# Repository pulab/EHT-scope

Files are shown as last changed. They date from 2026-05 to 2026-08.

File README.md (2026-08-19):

# EHT-scope
**Engineered heart tissue imaging platform with acquisition and analysis software**

The platform is designed to image engineered heart tissues suspended on flexible posts in a 24 well dish.

## Components

* **EHT-scope Hardware Build**: Instructions and schematics to build the imaging platform
* **Code**: Software for acquisition, tracking, and analysis
  * **EHT-acquire**: Code for data acquisition using EHT-scope hardware
  * **EHT-analyze**: MATLAB scripts to analyze post positions and calculate physiological parameters

## Workflow (MATLAB-Based)

1.  **Acquisition**: (`EHT-acquire_v2.bsh`): Automated 24-well plate imaging with pacing protocols using EHT-scope hardware
2.  **Motion Tracking** (`EHT_motion_tracker.m`): Template-based post position tracking
3.  **Force Analysis** (`multi_pacing_analysis.m`): Calculate force, contraction/relaxation kinetics, and beat metrics

## Key Features
- **No ImageJ dependency** - all tracking and analysis handled entirely in MATLAB
- **Automated batch processing** of multiple wells and pacing frequencies
- **Dynamic self-calibrating diastolic baseline** computation to auto-correct for tracking offsets
- **Physiological parameter extraction** (force, beat rate, kinetics, T50, C50, R50)
- **Customizable** for different tissue geometries and spacing (configured in `EHT_config.m`)

## Getting Started

See `Code/EHT-analyze/README.md` for detailed usage instructions and **critical template-drawing guidelines.**

## Example Data and Results

Example image sequences and representative results are available in the latest GitHub release:

https://github.com/pulab/EHT-scope/releases/latest

Download `Supplementary Data 4.zip` from the release assets. The archive contains:

- `Analysis_Code`: analysis code included with the supplementary package
- `Representative_Image_Sequences`: example raw image sequences
- `Results`: representative tracking and force-analysis output files

To run the example data, extract the zip file, add `Code/EHT-analyze` to the MATLAB path, and use the extracted `Representative_Image_Sequences` folder as the input data folder.

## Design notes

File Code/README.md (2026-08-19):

# EHT-scope Code - MATLAB Workflow
Authors: William Pu (EHT-acquire) and Kushaan Sharma (EHT-scope).

This folder contains all the code for the EHT-scope platform using a unified MATLAB workflow.

## Overview

The workflow consists of three main stages:
1. **Image Acquisition** - EHT-acquire: Automated imaging via MicroManager (BeanShell)
2. **Motion Tracking** - EHT-scope: Post position tracking using MATLAB Image Processing Toolbox
3. **Motion Analysis** - EHT-scope: Physiological parameter calculation in MATLAB

## Files

### EHT-acquire
#### Arduino Controller
- **EHT_controller.ino**: Arduino sketch for controlling optical pacer, focus motor, and illumination
#### Acquisition
- **EHT_acqure_v2.bsh**: BeanShell script for automated acquisition via MicroManager
- **BaslerCameraInitialize.bsh**: BeanShell script to initialize the Basler Camera

### Motion Tracking (MATLAB)
- **EHT-analyze/EHT_motion_tracker.m**: Main motion tracking function

### Force Analysis (MATLAB)
- **EHT-analyze/multi_pacing_analysis.m**: Main analysis script
- **EHT-analyze/analyze_EHT_with_figure.m**: Detailed analysis and plotting
- **EHT-analyze/post_force2.m**: Force calculation from post deflection
- **EHT-analyze/find_pv7.m**: Peak and valley detection
- **EHT-analyze/peakdet2.m**: Peak detection algorithm
- **EHT-analyze/sgolayfilt.m**: Savitzky-Golay filter
- **EHT-analyze/analyze_slopes.m**: Contraction/relaxation slope analysis
- **EHT-analyze/detect_maxmin.m**: Helper wrapper function
- **EHT-analyze/calculate_slopes.m**: Helper wrapper function

## Requirements

### MATLAB
- MATLAB R2016b or later
- Image Processing Toolbox

### MicroManager (for acquisition only)
- MicroManager 1.4
- Compatible camera and motorized stage

## Quick Start

### 1. Acquisition
Run `EHT_acqure_v2.bsh` in MicroManager to capture images.

### 2. Motion Tracking
```matlab
% In MATLAB, navigate to Code/EHT-analyze/
EHT_motion_tracker()
```

### 3. Force Analysis
```matlab
% In MATLAB
multi_pacing_analysis()
```

## Data Flow

```
Raw Images (TIF) 
    ↓ (MicroManager)
Image Folders + Metadata
    ↓ (EHT_motion_tracker.m)
Post Positions (TXT)
    ↓ (multi_pacing_analysis.m)
Force Metrics (TXT) + Plots (FIG)
```

## Documentation

See **EHT-analyze/README.md** for comprehensive documentation including:
- Detailed usage instructions
- Parameter descriptions
- Calibration procedures
- Troubleshooting guide
- Example workflows

## Advantages of MATLAB Workflow

✓ **No ImageJ dependency**: All processing in MATLAB  
✓ **Unified environment**: One platform for all analysis  
✓ **Powerful visualization**: MATLAB plotting and export  
✓ **Academic standard**: Widely used in research  
✓ **Reproducible**: Version-controlled analysis scripts  

## Support

For detailed help, see `EHT-analyze/README.md` in this directory.

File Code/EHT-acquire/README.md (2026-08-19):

# EHT-acquire
- code needed to run the EHT-scope hardware and automate acquisition from a 24-well plate
- requires Micromanager 1.4

## EHT_controller.ino
- arduino sketch to run the arduino user interface of EHT-scope

## EHT_acquire_v2.bsh
- Micromanager 1.4 beanshell script for automated acquisition

## BaslerCameraInitialize.bsh
- Micromanager 1.4 beanshell script to configure the Basler Camera

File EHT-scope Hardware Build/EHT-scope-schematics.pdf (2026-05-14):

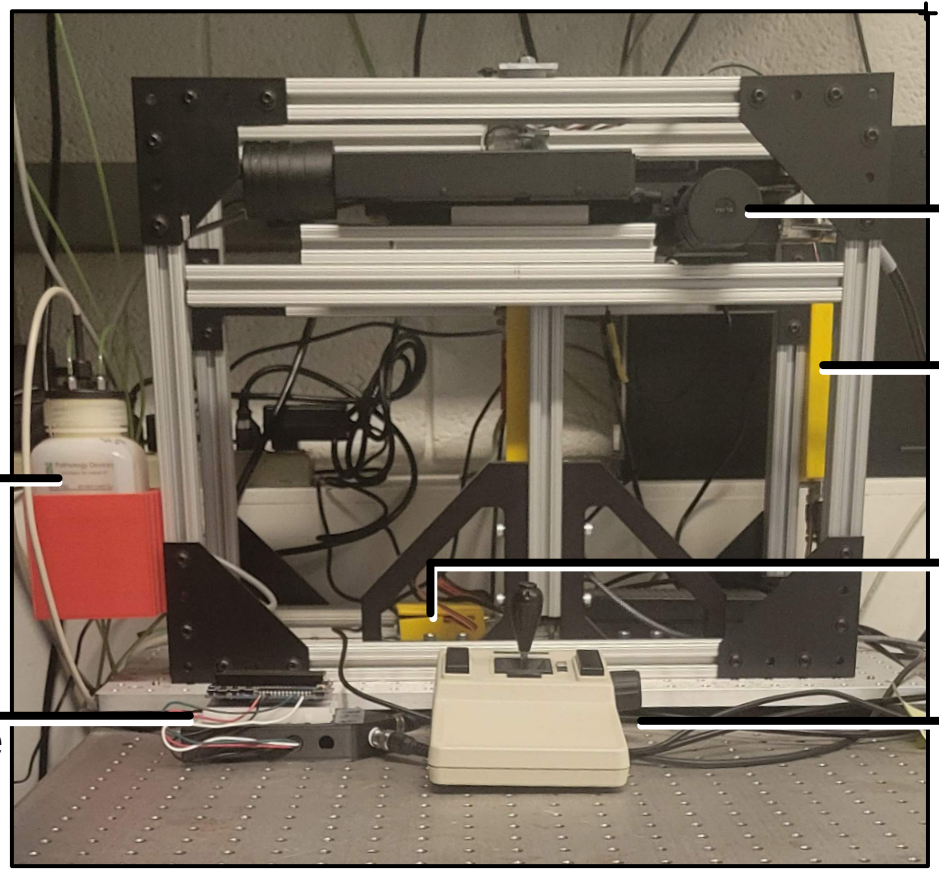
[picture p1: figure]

Mechanical
Stage (Prior)

LED power

Prior XY
stage

Actuator
Controller

Stage
Controller

Lens

Ring light (white light)
and lens mount

Blue light filter

Blue LEDs on
aluminum heatsink/
support

Camera

Camera Mount

Actuator Mount

Linear Actuator

a

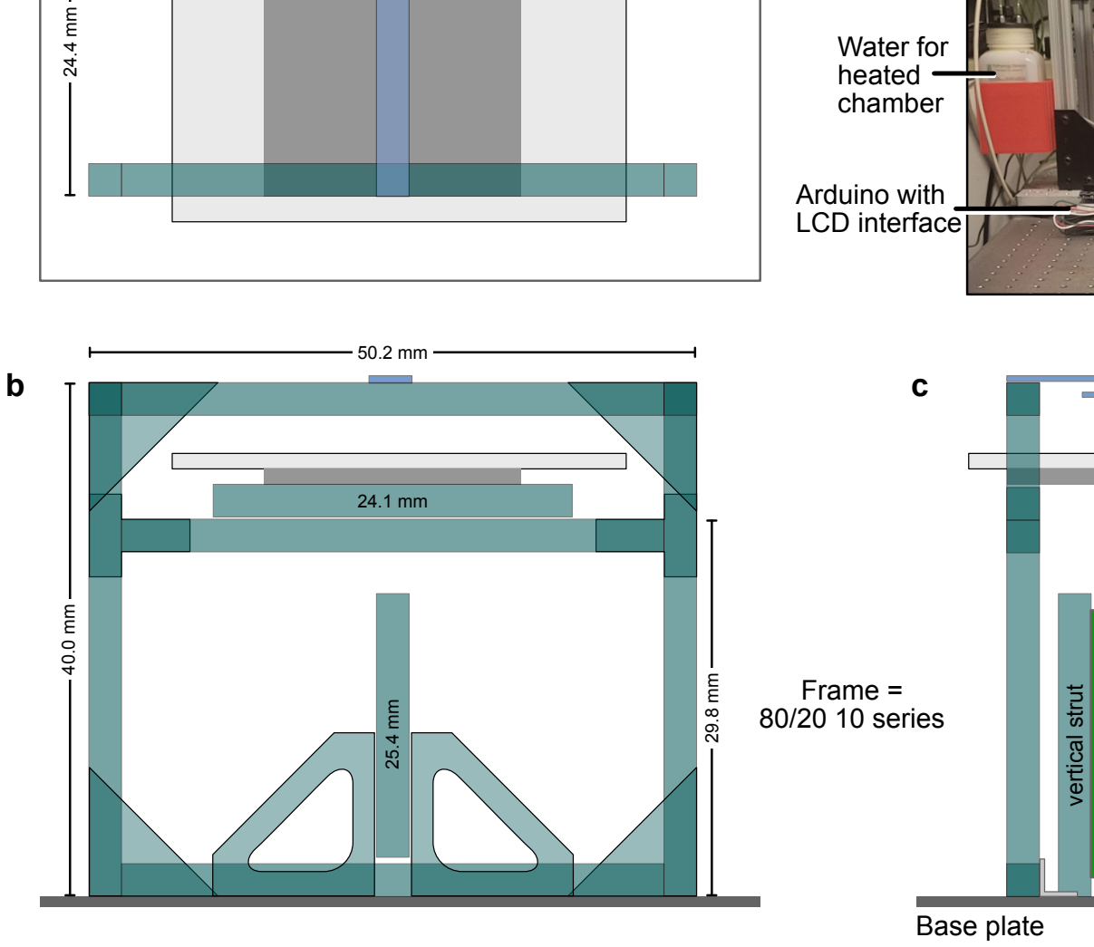
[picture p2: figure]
Base plate; Frame = 80/20 10 series; Water for heated chamber; vertical strut; Arduino with LCD interface

Figure 1. EHT assay device design. a-c. Schematic top (a), front (b), and side (c) views showing the 80/20 extruded aluminum frame supporting the mechanical stage. The side view details the camera attachment to a linear actuator through 3D printed mounts. A 3D printed attachment to the top of the lens holds a white LED ring light and a blue long-pass filter. The blue pacing LEDs are mounted above the stage under an aluminum heatsink/support. d. EHT assay device photo taken from the front.

d

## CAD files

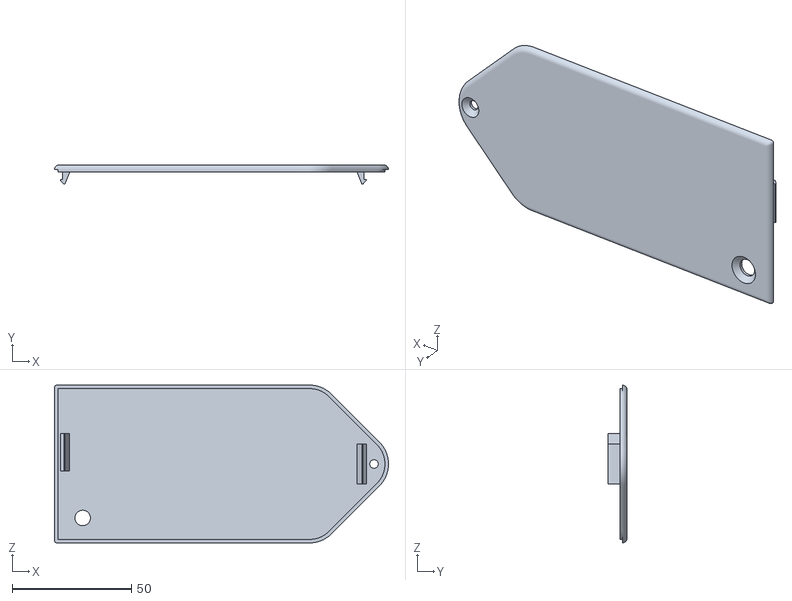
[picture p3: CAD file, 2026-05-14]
EHT-scope Hardware Build/Arduino simple 4 channel ttl top.stl
140.2 x 8.00 x 66.3

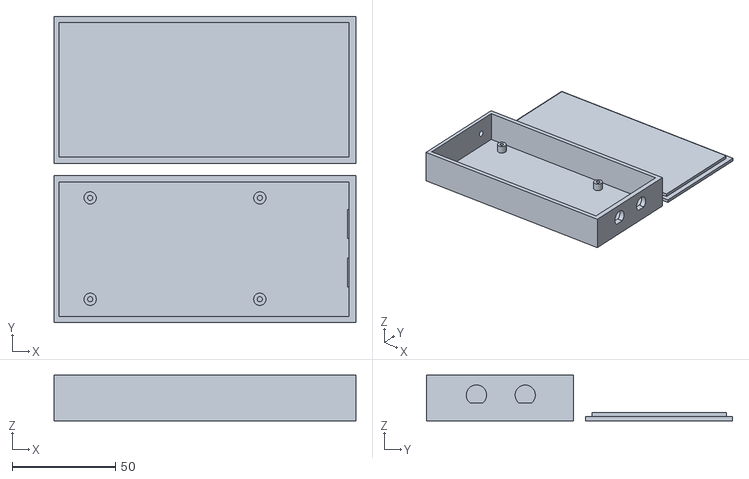
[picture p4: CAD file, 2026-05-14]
EHT-scope Hardware Build/LED_Power_holder.stl
146.0 x 148.0 x 22.0

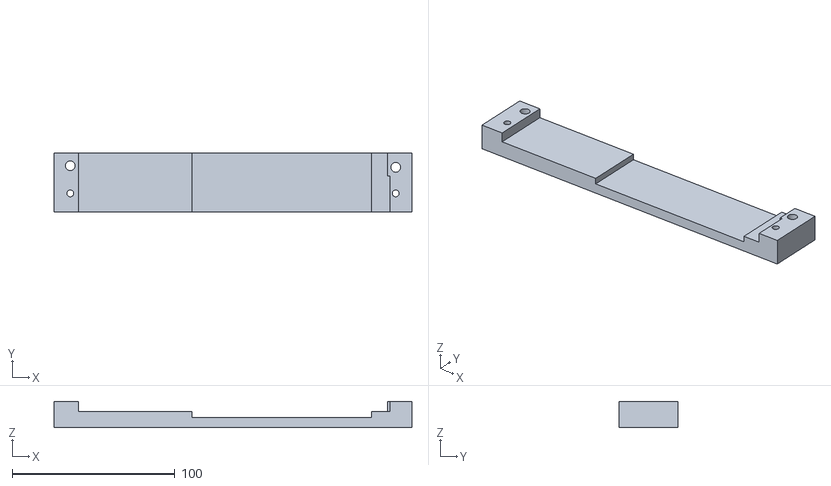
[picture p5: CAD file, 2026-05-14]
EHT-scope Hardware Build/ActuatorHolderV2.stl
220.0 x 36.0 x 16.0

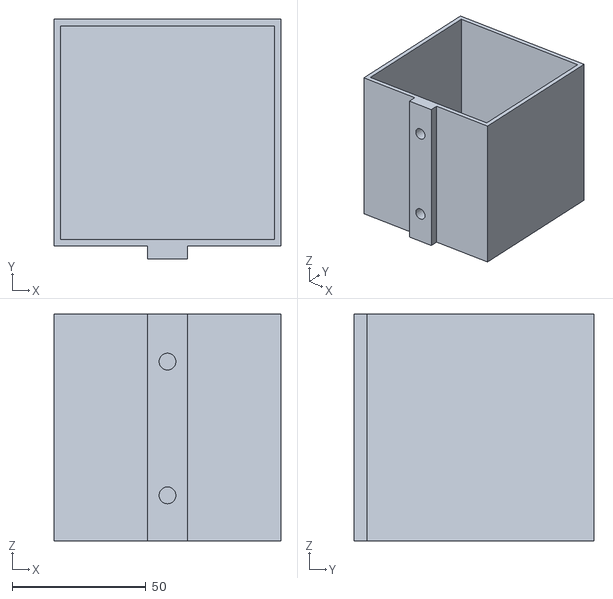
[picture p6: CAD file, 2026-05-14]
EHT-scope Hardware Build/stagetop bottle holder.stl
85.0 x 89.7 x 85.0

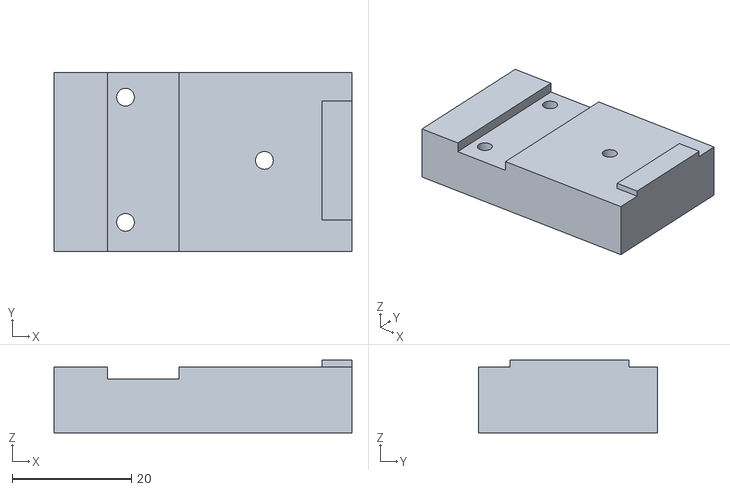
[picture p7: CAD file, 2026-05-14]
EHT-scope Hardware Build/CameraMountv2.stl
50.0 x 30.0 x 12.2

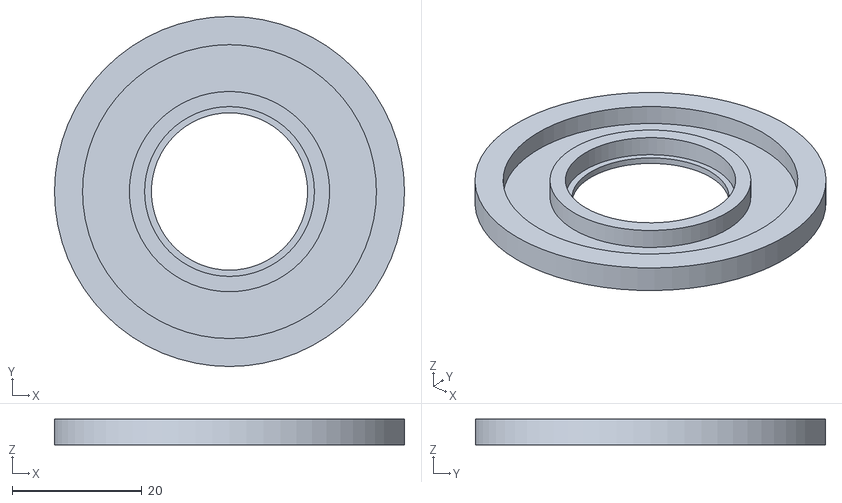
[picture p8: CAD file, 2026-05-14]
EHT-scope Hardware Build/LED_LPFilter_holder -- 54 mm -- slip.stl
53.9 x 53.9 x 4.00

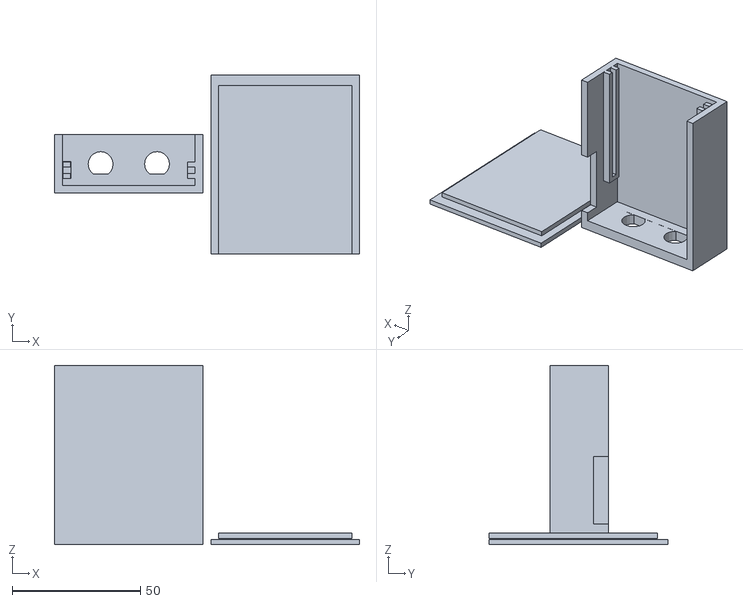
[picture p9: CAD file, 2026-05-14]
EHT-scope Hardware Build/LinearActuatorController_Holder.stl
119.0 x 70.0 x 70.0

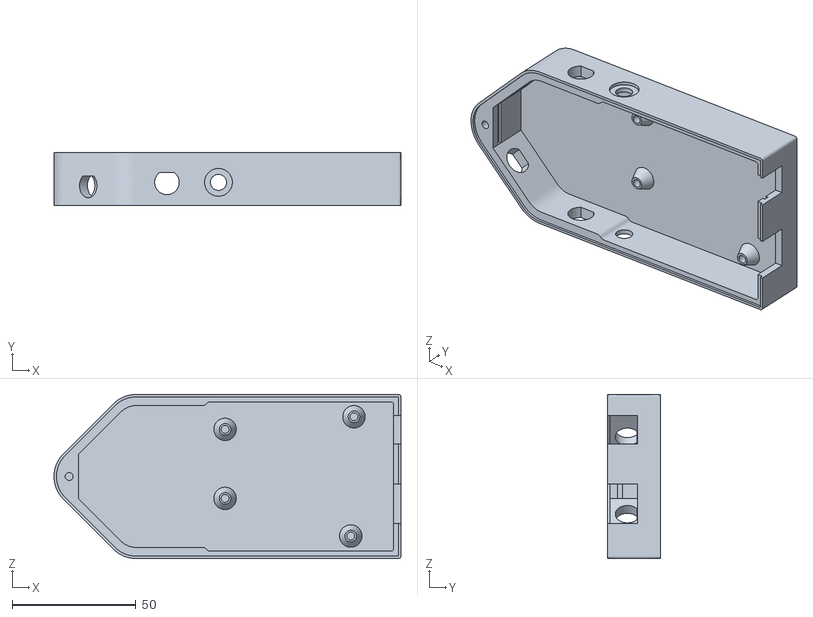
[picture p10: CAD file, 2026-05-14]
EHT-scope Hardware Build/Arduino simple 4 channel ttl bottom.stl
140.2 x 21.3 x 66.3

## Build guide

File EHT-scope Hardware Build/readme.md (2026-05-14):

**Introduction**

The EHT assay device consists of several components:

- A frame that supports a mechanical stage above a video camera. There is white light illumination for the video camera and a high intensity blue LED for optical pacing.
- An Arduino running software (EHT-controller) that controls the camera, optical pacer, and white light illumination.
- A PC connected to the mechanical stage and the Arduino. Using MicroManager as the hardware controller and the BeanShell script EHT-acquire, the PC automates multiwell acquisition.
- Post-acquisition video analysis using MATLAB (EHT_motion_tracker) to yield EHT post positions over time.
- Force analysis in MATLAB (analyze_EHT), which analyzes post position vs time to calculate contraction and relaxation kinetics and force.

**Software Workflow:**
1. Image acquisition: MicroManager with BeanShell script (`EHT_acqure_v2.bsh`)
2. Motion tracking: MATLAB (`EHT_motion_tracker.m`)
3. Force analysis: MATLAB (`analyze_EHT.m`)

All analysis is now performed in MATLAB for a unified workflow. See `Code/README_MATLAB.md` for detailed software documentation.

**Assembly of the EHT assay device.**

Refer to ItemList.xlsx and EHT-scope-schematics.pdf

1. **Assemble the EHT assay device frame (See Fig. 1)**

Assemble the frame for the device using 80/20 10 series profiles, following the schematics in Fig. 1. Cut the profiles to length using a miter saw with a blade for cutting aluminum. This frame holds the mechanical stage above the camera and lens and below the pacing LEDs. The frame dimensions should be adjusted to fit the select XY stage.

2. **Attach the frame to the aluminum base plate (See Fig. 1)**

Attach the rubber damping feet to the aluminum base plate.

Use the right angle brackets to attach the 80/20 frame to the base plate.

Use two 6” vertical brackets to attach the vertical strut to the base plate.

3. **Attach the mechanical stage to the frame (See Fig. 1)**

We used a spare Prior H101A stage. This stage was designed for an upright microscope and needed modifications to work in this inverted application. It would be better to use a stage designed for an inverted microscope.

4. **Assemble the camera and lens (See Fig. 2)**

3D print the mount that holds the ring light and long pass filter on the lens. Use a glue gun to attach the ring light and long pass filter to the mount. Solder long wires to the ring light. The mount fits into the threads on the end of the lens. Attach the lens to the camera. Mount the camera on the linear actuator using the 3D printed camera mount. Mount the linear actuator to the vertical strut using the 3D printed actuator holder. Wire the linear actuator to its controller and its AC/DC transformer, following the instructions on the Actuonix website. Solder the ground and signal wires to a BNC cabinet connector.

5. **Assemble the pacing LEDs (see Fig. 3 and 4)**

Place the Teflon sliders in the T-tracks on the top rails of the frame. Also put the stopper bolts into these T-tracks. Cut one aluminum bar so it spans the frame and a shorter aluminum bar about ½ the length of the first. Drill holes in the longer aluminum bar, one pair for the bolts on the Teflon sliders, and one pair to mount the shorter bar. Cut slots into the shorter bar so that its position can be adjusted with respect to the upper bar. Attach the 2 blue pacing LEDs using thermal epoxy. Solder long wires to the blue pacing LEDs. Snap the lens covers on the pacing LEDs. Mount the shorter bar under the longer using screws, springs, and wing nut. This will allow you to be able to adjust the height and location of the pacing lights so that it is centered above the camera and just above the top of the stage top incubator. Use the long wires to connect the pacing lights to the high-power LED drivers, mounted in the 3D printed LED driver case. Solder the LED driver inputs to BNC cabinet connectors. Pass the long wires from the ring light into the LED driver case and solder them to BNC cabinet connectors. Inside the LED driver case, connect the 12V AC/DC transformer to the LED drivers and connect the ring light AD/DC transformer to the long wires from the ring light.

6. **Assemble the Arduino (See Fig. 4)**

3D print the Arduino case. Build the RGB LCD shield, which is the user interface for the Arduino. Instructions on Adafruit website. Wire the Arduino as follows: Pin 5 for white LED ring light. Pin 6, Blue pacing LEDs. Pin 10, linear actuator. Each of these wires is soldered to the central terminal on a cabinet BNC connector, attached to the Arduino case. Solder a wire to each of the 3 outer BNC terminals. Solder the other end to a wire from the GND. Wire the RGB LCD shield. On the RGB shield board, we refer to the bottom row of 12 holes counting left to right, with the hole nearest the reset button being 12. Red from hole 3 to Arduino 5V. Black from hole 5 to Arduino GND (next to the 5V pin). Green from hole 11 to Arduino A4. White from hole 12 to Arduino A5. Use BNC connectors to connect the Arduino to the pacing LED driver, white LED ring light, and linear actuator.

Plug the Arduino into the computer using a USB cable. Upload EHT-controller.ino to the Arduino.

7. **Configure EHT-assay-device.**

Unplug and plug in the USB connector to the Arduino. The code should run. Use keys next to the LCD to select focus. Adjust the position of the camera using the up and down arrows on the Arduino so that the camera is focused on the EHT posts when they are placed within 24w dish inside the stage incubator. Adjust the height of the pacing assembly and center the pacing LEDs over the center of the lens. Make sure that the mechanical stage can move all of the well positions over the lens center.

8. **Install and configure micromanager.**

Install Basler camera pylon 6 SDK. Install micromanager 1.4. Configure it to use the Prior stage, the Basler camera, and the Arduino-Hub. Load and run the BeanShell code for EHT-acquire, which controls automated image acquisition. On the Arduino, select the “Run” option so that the computer can control the acquisition.

9. **Configure MATLAB for post motion analysis**

Install MATLAB (R2016b or later) with the following toolboxes:
- Image Processing Toolbox
- Curve Fitting Toolbox

The MATLAB code for motion tracking and force analysis is located in the `Code/EHT-analyze/` folder:
- **EHT_motion_tracker.m** - Analyzes EHT video images and yields a table of position vs time
- **EHT_motion_tracker_gui.m** - GUI interface for motion tracking
- **analyze_EHT.m** - Analyzes post position vs time to calculate contraction/relaxation kinetics and force

**Quick Start:**
```matlab
% In MATLAB, navigate to Code/EHT-analyze/
EHT_motion_tracker_gui()  % Run motion tracking with GUI
```

See `Code/README_MATLAB.md` for detailed installation and usage instructions.

**Note:** The previous ImageJ/Fiji-based workflow has been replaced with a unified MATLAB workflow for easier use and better integration.

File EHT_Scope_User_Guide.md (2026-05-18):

# EHT-Scope User Guide (Quick Start)
**Standardized Analysis Workflow for EHT Videos**

---

## 1. Before You Start
Make sure your data is organized correctly on your computer:
*   **Raw Videos**: Place your video folders inside the `TestingData` folder.
*   **Folder Names**: Ensure folders are named like this: `Acquire-EHT_WellName_PacingRate` (Example: `Acquire-EHT_A1_60`).

For the manuscript example data and results, download `Supplementary Data 4.zip` from the latest GitHub release:

https://github.com/pulab/EHT-scope/releases/latest

After extracting the zip file, use `Representative_Image_Sequences` as the input data folder. The `Results` folder contains representative tracking and force-analysis outputs.

---

## 2. Step 1: Tracking the Tissue (Motion Tracking)
To identify the posts in your video, run the following command in the MATLAB Command Window. 

**Note**: You must be in the main project folder.

```matlab
% 1. Add the code folder to your MATLAB path
addpath('Code/EHT-analyze');

% 2. Run the tracking command (This example tracks ALL folders in TestingData)
EHT_motion_tracker('Templates', 'TestingData', 'Results', true, 'Code/EHT-analyze/EHT_config.m', true, {});
```
*   **Post Selection**: A window will open for each new well. Click and drag boxes around the **left post** and **right post**.
*   **Automatic Matching**: The software will automatically apply your boxes to all pacing rates (0, 60, 120) for that well.

---

## 3. Step 2: Getting the Results (Force Analysis)
Once tracking is finished, run the analysis command:

```matlab
multi_pacing_analysis
```
When prompted, enter the full path to the `Results` folder created by the motion-tracking step.
*   **Individual Results**: Saved in the `Results` folder as `.txt` files for each tissue and pacing rate.
*   **Figures**: Saved in the `Results` folder as MATLAB `.fig` files.

---

## 4. Standard Settings
To change baseline settings, edit the file `Code/EHT-analyze/EHT_config.m`:
*   **Pixel Size**: Should be **67** (Pixels per mm).
*   **Diastolic Distance**: Should be **8.0** mm.

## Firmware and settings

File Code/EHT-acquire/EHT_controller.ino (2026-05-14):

#include <Adafruit_MCP4725.h>

#include <Adafruit_RGBLCDShield.h>
#include <Servo.h>
#include <Adafruit_NeoPixel.h>

#include <EEPROM.h>

#define OFF 0x0
#define RED 0x1
#define YELLOW 0x3
#define GREEN 0x2
#define TEAL 0x6
#define BLUE 0x4
#define VIOLET 0x5
#define WHITE 0x7 

#define TERM '\r'
#define TIMEOUT 2000
#define LED_COUNT 16
#define NEOPIXEL_ON 1
#define NEOPIXEL_OFF 0
#define FOCUS_addr_hi 0
#define FOCUS_addr_lo 1

Adafruit_RGBLCDShield lcd = Adafruit_RGBLCDShield();
Servo myservo;

const int NEOPIXEL = 5;
const int BLUE_LED = 6;
const int FOCUS = 10;
const int FRAME_TRIGGER = 2;
const int FRAME_TRIGGER_WIDTH = 2;

Adafruit_NeoPixel strip(LED_COUNT, NEOPIXEL, NEO_RGBW + NEO_KHZ800);

String mode = "Serial";
int menuSelection = 0;
char *menuItems[] = { "Run", "Rate", "Focus", "White On", "White Int", "Blue Int", "Blue PW","Serial","Sleep"};
int menuItemsLength=9;
int rate = 120;
const int increment = 10;
const int minRate = 30;
const int maxRate = 240;
int pulseWidth = 8;
int whiteIntensity = 100;
int blueIntensity = 100;
unsigned int paceTime = 60000/rate;
unsigned long lastPaceTime=0;
boolean paceState=false;
int paceInterval;
unsigned int frameTime = 40;
unsigned long lastFrameTime=0;
int servoPosition;
int minServoPosition=1500;
int maxServoPosition=1760;

String msg, cmd;
boolean serialRun=false;
int value;
int delta;

void setup() {
  Serial.begin(9600);
  Serial.setTimeout(TIMEOUT);
  strip.begin();
  strip.show();
  neoPixelIntensity(whiteIntensity);
  pinMode(BLUE_LED, OUTPUT);
  pinMode(FRAME_TRIGGER, OUTPUT);

  lcd.begin(16, 2);
  displayMenu();

  myservo.attach(FOCUS);
  myservo.writeMicroseconds(servoPosition);

  servoPosition = constrain(EEPROM.read(FOCUS_addr_hi)*16 + EEPROM.read(FOCUS_addr_lo),minServoPosition,maxServoPosition);
}

void loop() {

  uint8_t buttons = lcd.readButtons();

  if (mode=="TOP_MENU") {
    if (buttons) {
      if (buttons & BUTTON_UP) {
        menuSelection--;
        if (menuSelection<0)
          menuSelection = menuItemsLength-1;
      } else if (buttons & BUTTON_DOWN) { 
        menuSelection++;
        if (menuSelection >= menuItemsLength)
          menuSelection = 0;
      } else if (buttons & BUTTON_SELECT) {
        mode=menuItems[menuSelection];
        if (mode=="White On" || mode == "White Int" || mode=="Focus" || mode == "Run") {
          neoPixel(NEOPIXEL_ON);
          lastPaceTime=millis();
          paceState=false;
          lastFrameTime=millis();
          paceTime=60000/rate;
          paceInterval=paceTime;
        }
      }
      displayMenu();
      delay(300);
    }
  } else if (mode=="Rate") {
    if (buttons) {
      if (buttons & BUTTON_UP) {
        rate += increment;
        rate = constrain(rate,minRate,maxRate);
      } else if (buttons & BUTTON_DOWN) {
        rate -= increment;
        rate = constrain(rate,minRate,maxRate);
      } else if (buttons & BUTTON_SELECT) {
        mode="TOP_MENU";
      }
      displayMenu();
      delay(300);
    }
  } else if (mode=="Run") {
    if (buttons) {
      neoPixel(NEOPIXEL_OFF);
      digitalWrite(BLUE_LED,LOW);
      mode="TOP_MENU";
      displayMenu();
      delay(300);
    } else {
      if (millis()-lastPaceTime>paceInterval) {
        lastPaceTime=millis();
        if (paceState) {
          digitalWrite(BLUE_LED,LOW);
          paceInterval=paceTime;
          paceState=false;
        } else {
          analogWrite(BLUE_LED,map(blueIntensity,0,100,0,255));
          paceInterval=pulseWidth;
          paceState=true;
        }
      }
      if (millis()-lastFrameTime>frameTime) {
        lastFrameTime=millis();
        digitalWrite(FRAME_TRIGGER, HIGH);
        delay(FRAME_TRIGGER_WIDTH);
        digitalWrite(FRAME_TRIGGER, LOW);
      }
    }
  } else if (mode=="White On") {
    if (buttons) {
      neoPixel(NEOPIXEL_OFF);
      mode="TOP_MENU";
      displayMenu();
      delay(300);
    }
  } else if (mode=="Focus") {
    if (buttons) {
      if (buttons & BUTTON_UP) {
        servoPosition+=10;
      } else if (buttons & BUTTON_DOWN) {
        servoPosition-=10;
      } else if (buttons & BUTTON_SELECT) {
        myservo.writeMicroseconds(servoPosition-200);
        delay(1000);
        myservo.writeMicroseconds(servoPosition);
        mode = "TOP_MENU";
        neoPixel(NEOPIXEL_OFF);
        mode="TOP_MENU";
      } else if (buttons & BUTTON_RIGHT) {
        myservo.writeMicroseconds(servoPosition-200);
        delay(1000);
        myservo.writeMicroseconds(servoPosition);
      }
      servoPosition=constrain(servoPosition,minServoPosition,maxServoPosition);
      saveFocus(servoPosition);
      displayMenu();
    }
  } else if (mode=="Serial") {
    if (Serial.available() > 0) {
      msg = Serial.readStringUntil(TERM);
      msg.trim();
      cmd = msg.substring(0,4);
      if (msg.length() > 4) {
        value=msg.substring(4).toInt();
        Serial.println(value);
        }
      if (cmd == "IDaa") {
        Serial.println("EHT");
      } else if (cmd == "WHIT")
        neoPixel(NEOPIXEL_ON);
      else if (cmd == "STOP") {
        neoPixel(NEOPIXEL_OFF);
        serialRun=false;
        digitalWrite(BLUE_LED,LOW);
        displayMenu();      
      } else if (cmd == "FaUP" || cmd == "FaDN") {
        if (cmd == "FaUP")
          servoPosition+=value;
        else
          servoPosition-=value;
        servoPosition=constrain(servoPosition,minServoPosition,maxServoPosition);
        myservo.writeMicroseconds(servoPosition-200);
        delay(1000);
        myservo.writeMicroseconds(servoPosition);        
      } else if (cmd == "RUNa") {
          serialRun=true;
          lcd.clear();
          lcd.setBacklight(RED);
          lcd.print("Serial run");
          lcd.setCursor(0,1);
          rate=value;
          lcd.print(String(rate)+"  ");
          neoPixel(NEOPIXEL_ON);
          lastPaceTime=millis();
          paceTime=60000/rate;
      } else {
        Serial.println(cmd);
      }
    } else if (buttons) {
      mode="TOP_MENU";
      serialRun=false;
      neoPixel(NEOPIXEL_OFF);
      digitalWrite(BLUE_LED,LOW);
      displayMenu();  
    } else if (serialRun) {
      if (millis()-lastPaceTime>paceInterval) {
        lastPaceTime=millis();
        if (paceState) {
          digitalWrite(BLUE_LED,LOW);
          paceInterval=paceTime;
          paceState=false;
        } else {
          analogWrite(BLUE_LED,map(blueIntensity,0,100,0,255));
          paceInterval=pulseWidth;
          paceState=true;
        }
      }
      if (millis()-lastFrameTime>frameTime) {
        lastFrameTime=millis();
        digitalWrite(FRAME_TRIGGER, HIGH);
        delay(FRAME_TRIGGER_WIDTH);
        digitalWrite(FRAME_TRIGGER, LOW);
      }
    }
  } else if (mode=="Blue Int") {
    if (buttons) {
      if (buttons & BUTTON_UP) {
        blueIntensity+=10;
      } else if (buttons & BUTTON_DOWN) {
        blueIntensity-=10;
      } else if (buttons & BUTTON_SELECT) {
        mode="TOP_MENU";
      }
      delay(300);
      blueIntensity=constrain(blueIntensity, 10, 100);
      displayMenu();
    }
  } else if (mode=="White Int") {
    if (buttons) {
      if (buttons & BUTTON_UP) {
        whiteIntensity+=10;
      } else if (buttons & BUTTON_DOWN) {
        whiteIntensity-=10;
      } else if (buttons & BUTTON_SELECT) {
        neoPixelIntensity(whiteIntensity);
        mode="TOP_MENU";
      }
      delay(300);
      whiteIntensity=constrain(whiteIntensity, 10, 100);
      neoPixelIntensity(whiteIntensity);
      if (mode=="TOP_MENU")
        neoPixel(NEOPIXEL_OFF);
      else
        neoPixel(NEOPIXEL_ON);
      displayMenu();
    }
  } else if (mode=="Blue PW") {
    delta=pulseWidth/5;
    if (buttons) {
      if (buttons & BUTTON_UP) {
        pulseWidth+=delta;
      } else if (buttons & BUTTON_DOWN) {
        pulseWidth-=delta;
      } else if (buttons & BUTTON_SELECT) {
        mode="TOP_MENU";
      }
      delay(300);
      pulseWidth=constrain(pulseWidth, 5, 50);
      displayMenu();
    }
  } else if (mode=="Sleep") {
    lcd.noDisplay();
    lcd.setBacklight(OFF);
    while (!lcd.readButtons())
       delay(1000);
    lcd.display();
    mode="TOP_MENU";
    menuSelection=0;
    displayMenu();
    delay(300);
    buttons=lcd.readButtons();
  }
}

void displayMenu() {
  lcd.clear();
  lcd.setBacklight(BLUE);
  lcd.setCursor(0,0);
  if (mode=="TOP_MENU") {
    lcd.print("UpDn SEL=Select");
    lcd.setCursor(0,1);
    lcd.print(menuItems[menuSelection]);
  } else if (mode=="Run") {
    lcd.setBacklight(RED);
    lcd.print("RUN  bttn to stop");
    lcd.setCursor(0,1);
    lcd.print(String(rate)+"  ");
  } else if (mode=="Rate") {
    lcd.print("Rate UpDn=chg");
    lcd.setCursor(0,1);
    lcd.print(String(rate)+" bpm  SEL=set");
  } else if (mode=="White On") {
    lcd.print("White Light");
    lcd.setCursor(0,1);
    lcd.print("Bttn to stop");
  } else if (mode=="Focus") {
    lcd.print("Focus UpDn=chg");
    lcd.setCursor(0,1);
    lcd.print(String(servoPosition)+" Fwd=try SEL");
  } else if (mode=="Serial") {
    lcd.setBacklight(GREEN);
    lcd.print("Serial port");
    lcd.setCursor(0,1);
    lcd.print("Bttn to stop");
  } else if (mode=="Blue Int") {
    lcd.print("Blue Int UpDn=chg");
    lcd.setCursor(0,1);
    lcd.print(String(blueIntensity)+"   SEL=set");
  } else if (mode == "White Int") {
    lcd.print("White Int UpDn=chg");
    lcd.setCursor(0,1);
    lcd.print(String(whiteIntensity)+"  SEL=set");
  } else if (mode=="Blue PW") {
    lcd.print("Blue PW UpDn=chg");
    lcd.setCursor(0,1);
    lcd.print(String(pulseWidth)+"   SEL=set");
  } else if (mode=="Sleep") {
    lcd.print("Sleep");
    lcd.setCursor(0,1);
    lcd.print("Key to wake");
    delay(5000);
  } else {
    lcd.print("Error: bad mode");
    lcd.setCursor(0,1);
    lcd.print(mode);
  }
}

void neoPixel(int OnFlag) {
uint32_t color;
  if (OnFlag==NEOPIXEL_ON) {
    color=strip.Color(0,0,0,255);
  } else {
    color=strip.Color(0,0,0,0);
  }
  for (int i=0;i<strip.numPixels(); i++) {
    strip.setPixelColor(i,color);
    strip.show();
  }
}

void neoPixelIntensity(int value) {
  strip.setBrightness(map(value,0,100,0,255));
}

void saveFocus(int dec) {
  EEPROM.write(FOCUS_addr_lo,dec % 16);
  EEPROM.write(FOCUS_addr_hi,dec / 16);
}

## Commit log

2026-05-14 Initial Clean Commit: EHT Analysis Core Files
    [ActuatorHolderV2.stl, Arduino simple 4 channel ttl bottom.stl, Arduino simple 4 channel ttl top.stl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]
2026-10-28 Add videos and smoothing that handles dropped frames
    - mm2vfr.py (in EHT-analyze): makes .mp4 videos of the image sequences
    with a scale bar, timer and well label, each frame at its recorded time;
    --avi writes an .avi instead. Install and use steps in the README
    - Example_Videos: .mp4 and .avi videos of the five example sequences
    - Frame times now come from TimeReceivedByCore in metadata.txt
    (ElapsedTime-ms is occasionally stamped up to ~90 ms late); tracker
    reads each time from its own FrameKey entry
    - Smoothing now uses a fixed time window (sgolay_time.m) instead of a
    fixed number of frames, so dropped frames do not distort it
    - sg_window_size (frames) replaced by sg_window_s (se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
